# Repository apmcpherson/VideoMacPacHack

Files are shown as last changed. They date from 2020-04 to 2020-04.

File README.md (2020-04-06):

# VideoMacPacHack

The VideoMacPacHack is a clone of the Video Mac Pac, a PDS video card for the Macintosh Portable designed in 1991 by Computer Care Inc. The Video Mac Pac provides monochrome (1-bit) video on an external display, with several resolutions selectable by a control panel.

The VideoMacPacHack aims to replicate the Video Mac Pac using original parts where possible, with modern substitutions in  cases where original parts are hard to source (e.g. GAL, miniature relay), or where the original design was unknown (the video adapter board).

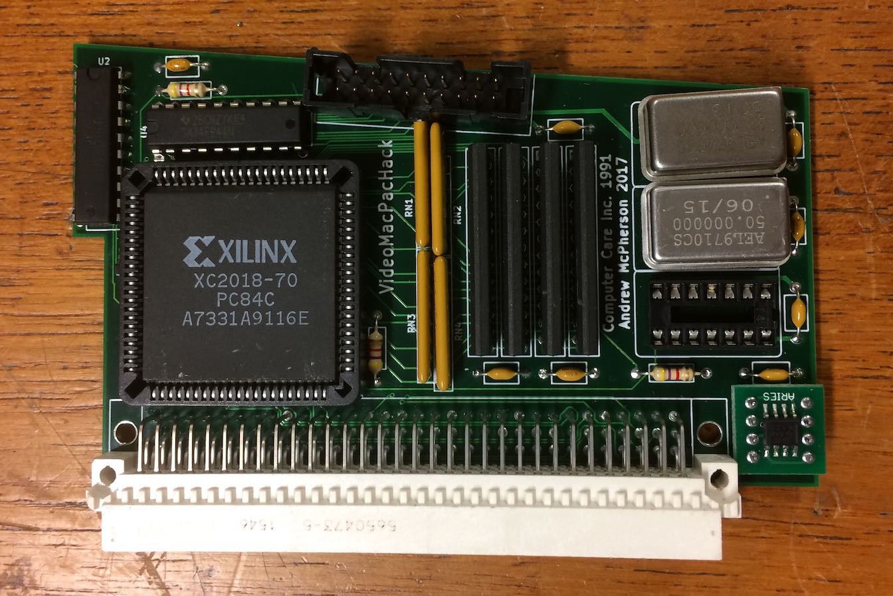
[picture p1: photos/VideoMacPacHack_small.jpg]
VideoMacPacHack


## Contents

* `hardware/VideoMacPac`: PCB design for the VideoMacPacHack, 4 layers, made in Kicad
* `hardware/VGA_adapter`: PCB design for the VGA breakout board, 2 layers, made in EAGLE
* `software`: Video Mac Pac Control Panel, needed to load the card firmware and select resolution
* `photos`: Photos of the original and clone card
* `documentation`: Technical information on the hardware and software

## System Requirements and Operation

The VideoMacPacHack fits the PDS slot of the Macintosh Portable. It has been successfully tested in both M5120 (non-backlit) and M5126 (backlit) Portables. Based on the address space used by the card, it will probably only work on Portables with less than 8MB of RAM installed.

The VideoMacPacHack (like the original Video Mac Pac) requires its associated control panel to run (see `software`). The external screen will become active when the control panel loads, provided the external video adapter is attached at boot. If the Portable is put to sleep, the external display will not work until reboot.

## Acknowledgments

The Video Mac Pac was created by Computer Care Inc. in 1991, apparently based on the Lapis DisplayServer.

The VideoMacPacHack was designed by [Andrew McPherson](https://github.com/apmcpherson) with encouragement from [Tom Stepleton](https://github.com/stepleton) based on hardware in his collection. In the interest of historical preservation it is released into the public domain, with no warranty of any sort.

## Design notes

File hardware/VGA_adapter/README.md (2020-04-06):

# VideoMacPac video adapter

These design materials are in the public domain, with no warranty whatsoever. See `documentation` on this repository for further design notes and `photos` for a photo of the assembled board.

## EAGLE files

* `VideoMacPac_adapter.sch`: EAGLE schematic
* `VideoMacPac_adapter.brd`: EAGLE PCB design
* `schematic.png`: image of the schematic

## Gerbers

This is a 2-layer PCB which can be fabricated from the files in the `gerbers` directory. It is a simple design which can be made on a mill with no soldermask as long as it has plated-through holes. The most important files are:

* `copper_top.gbr`: top copper
* `copper_bottom.gbr`: bottom copper
* `profile.gbr`: board outline
* `drill_1_16.xln`: Excellon drill file

## Bill of Materials

| Name | Value |
| --- | --- |
| C1-C2 | 0.1uF 0603 capacitors |
| IC1 | 74LVC245 (20-SOIC) bus transceiver |
| IC2 | MCP1700-3302T (SOT23) 3.3V regulator  |
| J1 | DB25 female |
| J2 | HD15 (VGA) female |
| R1-R3 | 133 ohm 0603 resistors |
| R4-R6 | 150 ohm 0603 resistors |
| R7 | 100 ohm 0603 resistor (could use 150) |

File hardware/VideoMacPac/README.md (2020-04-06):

# VideoMacPacHack

These design materials are in the public domain, with no warranty whatsoever. See `documentation` on this repository for further design notes.

## Kicad files

* `VideoMacPac.pro`: Kicad project
* `VideoMacPac.sch`: Kicad schematic
* `VideoMacPac.kicad_pcb`: Kicad PCB design
* `VideoMacPac_schematic.pdf`: Schematic in PDF format

## Gerbers

This a 4-layer PCB which can be fabricated from the files in the `gerbers` directory.

* `VideoMacPac-F.Cu.gbr`: top copper
* `VideoMacPac-In1.Cu.gbr`: inner layer 1 copper
* `VideoMacPac-In2.Cu.gbr`: inner layer 2 copper
* `VideoMacPac-B.Cu.gbr`: bottom copper
* `VideoMacPac-F.SilkS.gbr`: top silkscreen
* `VideoMacPac-F.Mask.gbr`: top soldermask
* `VideoMacPac-B.Mask.gbr`: bottom soldermask
* `VideoMacPac-Edge.Cuts.gbr`: board outline
* `VideoMacPac.drl`: Excellon drill file

## Bill of Materials

| Name | Value |
| --- | --- |
| C1-C8 | 0.1uF axial capacitors |
| J1 | 20-pin IDC header |
| J2 | 96-pin right-angle EuroDIN |
| R1-R4 | 4.7k resistors |
| RN1-RN2 | 3x47 ohm SIP resistor networks |
| RN3-RN4 | 4x47 ohm SIP resistor networks |
| U1 | XC2018-100-PC84 (faster can be used) |
| U2 | 74F521 (DIP) |
| U3 | 74AHCT1G00 (SOT23) |
| U4 | 74F244 (DIP) -- do not substitute |
| U5-U8 | MT42C4064Z-12 (faster can be used) |
| U9 | TPS2030 (DIP) |
| X1 | 36MHz 4-pin oscillator |
| X2 | 50.35MHz 4-pin oscillator |
| X3 | 57.2832MHz 4-pin oscillator |

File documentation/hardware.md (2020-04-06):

# Video Mac Pac hardware

The following document is based on an analysis and reverse engineering of the Video Mac Pac board. To date we have not found any original documentation on this design.

## Operation overview

The Video Mac Pac, designed in 1991 by Computer Care Inc., is a PDS expansion card for the Macintosh Portable (M5120 and M5126) that provides a second video output in addition to the Portable’s built-in screen. It supports 1-bit video at several resolutions:

* 640x872 (Apple Portait Display)
* 640x872 (Sunkyung FPD)
* 640x872 (Samsung FPD)
* 640x480 (Apple Monochrome Display)
* 640x480 (VGA)
* 800x600 (Super VGA)
* 528x348 (Mono TTL)
* 272x208 (TV/VCR)

These resolutions are selectable through the Video Mac Pac control panel which must be installed for the card to work.

The hardware design and software drivers appear to be closely related to the Lapis DisplayServer-SE video card. The card is based on a Xilinx CPLD whose firmware is loaded at boot by the control panel, along with VRAM and some glue logic for interfacing to the PDS slot and to the display.

## CPLD

The Video Mac Pac is based on the Xilinx `XC2018-100PC84` CPLD, which has the following specifications: 

* 84-pin PLCC package 
* 5V logic
* 1800 gates
* 74 I/Os
* 100ns toggle rate 

The size of a program configuration on the XC2018 is 17878 bits. There is no non-volatile storage either on the XC2018 or elsewhere on the Video Mac Pac, meaning that the CPLD configuration is downloaded by the Macintosh on power-up.

On the VMP, the XC2018 mode pins `M0, M1, M2` are configured as `101`, corresponding to Peripheral mode. In this mode, the program is clocked in 1 bit at a time on the `DIN` and `WRT` pins.

For comparison, the Lapis DisplayServer-SE is also based on the XC2018. The SE-DPD (capable of driving dual page displays) instead uses the `XC3020-70-PC84`. 

## VRAM

The VMP uses four Micron `MT42C4064Z-12` 64kx4 VRAM ICs. These are in a 24-pin ZIP package (i.e. SIP with staggered leads). Each VRAM chip handles 4 bits of a 16-bit data word. 

The CPLD maps the VRAM to the memory address space from `$720000` to `$73FFFF` (128k bytes in total).

## GAL

The CPLD must be programmed by the Macintosh using the Video Mac Pac control panel. A `GAL16V8-25LNC` IC on the board implements an address decoder for address `$740200` (binary `0111 010x xxxx xx1x xxxx xxxx`). 

The GAL also takes as input a sense line (active high) from the external video dongle. When the dongle is connected, address `$740200` is matched and `AS/` is low, the output (tied to the `WRT` pin on the CPLD) goes low. This feature is used to program the CPLD after power-on, after which point further communication takes place directly to the CPLD via the bus on the PDS slot.

If the dongle is not connected when the control panel loads, the CPLD will not be programmed and the video card will not operate until a restart takes place.

## PDS slot

See Apple's *Designing Cards and Drivers for the Macintosh Family* for the pinout of the Macintosh Portable PDS slot. The following pins of the PDS slot connect to the CPLD:

* Clock signal `16M`
* All address lines `A23-A0`
* Data line `D0` (connected to `DIN` to program the CPLD)
* Address strobe `/AS`
* Data strobes `/UDS` and `/LDS`
* Read/write signal `R/W`
* Acknowledge signals `/DTACK` and `/EXT.DTACK`
* Reset signal `/SYS.RST`

The following parts of the PDS slot connect directly to the VRAM:

* Data lines `D15-D0`, 4 bits per IC

All other VRAM pins are connected via the CPLD.

## Relay

The VMP contains a miniature 5V relay which is switched by way of the PDS signal `5/0V`. This powers down the card when the Portable goes to sleep.

When the Portable wakes from sleep, the CPLD program will be lost and it appears that a power cycle is required to enable the external screen.

## Oscillators

The VMP has 3 oscillator cans: 36MHz, 50.35MHz, 57.2832MHz. The 36MHz oscillator is socketed, while the other two are soldered. One of the three oscillator signals is chosen by the CPLD depending on the screen resolution. These provide the pixel clock for the video output.

The oscillators are not powered directly on the board. Rather, power to the oscillators is routed to a pin on the external video dongle connector, and the dongle routes the power back to the oscillators. This appears to be a power saving measure when the dongle is not connected.

In addition to the three oscillators, the card receives a 16MHz clock from the PDS slot.

## Outputs

The CPLD generates eight output logic signals which are buffered through a `74F244` octal buffer. These signals include:

* Three video signals. Our testing showed that these three always generate the same signal, as the card is 1-bit monochrome, but perhaps keeping separate signals was intended for a future design which would be full colour.
* Horizontal and vertical sync
* Three other signals which measure as constant high or low depending on the chosen resolution. These may have performed control functions for an external dongle (now lost).

The signals appear on a 20-pin header with the following pinout:

| pin | description | pin | description |
| --- | --- | --- | --- |
| 1 | oscillator +5V | 2 | +5V out |
| 3 | ground | 4 | sense input |
| 5 | ground | 6 | HSYNC |
| 7 | ground | 8 | VSYNC |
| 9 | ground | 10  | unknown 1 |
| 11  | ground | 12  | video 1 |
| 13  | ground | 14  | video 2 |
| 15  | ground | 16  | video 3 |
| 17  | ground | 18  | unknown 2 |
| 19  | ground | 20  | unknown 3 |

## Video Adapter Dongle

The VMP has a 20-pin IDC header, which connects by a ribbon cable to a DB25 male connector mounted in the rear cover of the Portable. This presumably connects to a dongle which provides the last step of signal conditioning and the correct pinout for the monitor in question.

We do not have the original dongle, however based on experimentation we have worked out its probable functions:

* The dongle provides a loopback between the +5V power supply and the power input to the oscillators. This is presumably to reduce power consumption when the dongle isn’t connected and the card is not in use.
* The DB25 contains a sense line to the GAL which is responsible for programming the CPLD. On the dongle, this line is pulled up to +5V, allowing the GAL to be programmed and the card to become operational only when the dongle is connected at boot.
* The dongle may provide level-shifting for driving analog monitors (e.g. VGA, Apple 13”). For TTL monitors a different dongle might have been used which passed through the video signal directly.

The pinout of the DB25 male is as follows:

| pin | description | pin | description |
| --- | --- | --- | --- |
| 1 | oscillator +5V | 14  | +5V out |
| 2 | ground | 15  | sense input |
| 3 | ground | 16  | HSYNC |
| 4 | ground | 17  | VSYNC |
| 5 | ground | 18  | unknown 1 |
| 6 | ground | 19  | video 1 |
| 7 | ground | 20  | video 2 |
| 8 | ground | 21  | video 3 |
| 9 | ground | 22  | unknown 2 |
| 10  | ground | 23  | unknown 3 |
| 11  | n/c | 24  | n/c |
| 12  | n/c | 25  | n/c |
| 13  | n/c | | |

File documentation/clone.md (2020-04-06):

# VideoMacPacHack

The following are implementation notes on cloning the Video Mac Pac PDS expansion card. The schematic and board layout can be found in the `hardware/VideoMacPac/` directory in this respository.

## Schematic

The schematic of the VideoMacPacHack conforms as closely as possible to the original VMP, with a few exceptions:

### Address decoder

On the VMP, a `GAL16V8` implements a relatively straightforward address decoder with 10 inputs (9 address lines plus an active sense signal) and 1 output (to the CPLD `WRT` pin). To avoid the need to recreate this custom IC, standard logic can be used instead. The basis of the current design is a `74F521` 8-bit address decoder. In addition to its 8 logic inputs, it has a 9th `OE/` input which can be used for one additional bit of decoding. 

However, one further bit is still required to replicate the functionality of the GAL. Because board space does not allow another DIP IC, a single-gate SMT IC is used instead: `74AHCT1G00`, a single 2-input NAND gate.

### Power switch

Miniature relays have been supplanted by analog power switch ICs. This design uses a `TPS2030` IC to achieve the same effect as the original relay. A DIP package is used in the VMPH design. However, SMT versions of the part appear to be more widely available and can be used with a DIP-SMT adapter.

### 74F244

This is a place where the original design should not be changed.

Initial experiments exchanged the `74F244` buffer IC for a nearly-equivalent `74HC244`. However, we found that the longer and more variable propagation delay on the `74HC244` caused vertical edges to show colour tints, as the edges on the three video channels were no longer aligned (the R, G and B lines have separate logic signals from the CPLD). The original 74F244 does not exhibit this problem.

## PCB Layout

The mechanical layout of the PCB follows the original VideoMacPac design, which is in turn based on Apple’s specifications in the Guide to the Macintosh Family Hardware. The component layout is broadly similar to the original.

The PCB is a 4-layer design, like the original VMP. The trace routing is electrically identical but does not follow the same geometry as the original. The original VideoMacPac design largely avoids vias, with traces crossing layers at existing through-hole pads. The VMPH alternative routing was done relatively quickly and has not sought to optimise the layout in this way.

The VMPH design attempts to use through-hole parts wherever possible. It was necessary to make a single exception for space reasons: U3 (`74AHCT1G00`), a single NAND gate which is used to provide one extra input to the address decoder in U2.

On the other hand, the video adapter dongle is made with SMT ICs and passives for compactness.

## Notes on Bill of Materials 

The VideoMacPacHack requires the following historical parts, which can sometimes be found as new old stock:

* 1x `XC2018-100-PC84` (84-pin PLCC): Xilinx CPLD
* 4x `MT42C4064Z-12` (24-pin ZIP): VRAM
* 5V 4-pin oscillator cans: 36MHz, 50.35MHz, 57.2832MHz (see below)

### CPLD

A `XC2018-70` was used in place of the `XC2018-100` with no adverse effects.

### VRAM and resistor networks

A `MT42C4064Z-10` was used in place of the `MT42C4064Z-12` in prototypes with no adverse effects.

The VRAM connects to the PDS data lines, but most signals go to the CPLD by way of 47 ohm resistors. On the VMP, 4 SIP resistor networks are used: two with 4 elements, two with 3 elements. If 3-element resistor networks are hard to find, 4-element versions can be used in those slots with the two pins on the end cut off.

### Oscillators

5V DIP oscillator cans are no longer available in as many frequencies as they once were. New old stock may need to be found for these frequencies. In most cases, similar but non-identical frequencies can be used with the effect of changing the refresh rate of the resolution. Driving a modern LCD monitor this would likely not be a problem. 

There appear to be limits to how far the frequencies can be stretched: for example, putting a 50MHz crystal in place of the 36MHz crystal produces no output at the affected resolutions.

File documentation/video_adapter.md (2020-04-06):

# Video Adapter Dongle

An adapter board is necessary to connect from the DB25 male on the back of the Portable to the monitor. The original dongle for the Video Mac Pac was lost, so this reconstruction is based on its apparent principles of operation and almost certain differs substantially from the original.

See the `hardware/VGA_adapter/` directory in this repository for the schematic and board layout of the adapter. 

## Detection Circuit

Connecting pins 14 and 15 on the DB25 (pins 2 and 4 on the 20-pin IDC) holds the sense line high and signals the presence of the dongle. 

In the schematic, a 100 ohm resistor is used between these as a precaution in case of incorrect insertion of the dongle, but this could probably be replaced with a simple short.

## Oscillator Power

Connecting pins 1 and 14 on the DB25 (pins 1 and 2 on the 20-pin IDC) provides +5V power to the oscillators which are needed to generate the video pixel clock.

## Buffering and Level Shifting

All signals from the card are 5V TTL. VGA signals need to be 0.7V or 1.0V maximum, depending on the standard. Level shifting is therefore required for the video signals. 

The sync signals remain at TTL levels and are passed through unchanged to the VGA connector.

### 3.3V regulator

While a simple voltage divider could reduce the 5V TTL video signal to the correct level, we find that the 5V line on the Portable fluctuates under load, which results in brightness variations and sometimes noise on the picture.

Instead, a 3.3V regulator is used to generate a stable reference voltage for the video signals. Each of the three video signals is buffered by a `74LVC245` level shifter, which produces 3.3V outputs. These are in turn divided down by a resistive voltage divider to meet VGA level and impedance requirements.

### Impedance

VGA expects a signal of up to 0.7V (1.0V in some variations), and an impedance of 75 ohms. The `74LVC245` has a rated output impedance of 15 ohms per buffer. We therefore use 133 ohms in series (closest available value to 135 ohms) and 150 ohms in parallel to produce a raw (unloaded) output of 3.3V/2 = 1.65V, with a source impedance of 150/2 = 75 ohms. When the monitor is connected, the 75 ohm load impedance reduces the video signal to 1.65V/2 = .825V.

For comparison: examining the video adapters for the Lapis DisplayServer cards shows that they used 150 ohms in series and 150 ohms in parallel from a 5V source to generate the video signal.

### Alternative approach

Three separate logic signals are used for the R, G, and B lines, which ultimately derive from three different pins on the CPLD. Slight timing shifts between the pins result in messy vertical edges in the image, with colour tints to the left or right of the line. 

In our later investigations, we found that the `74HC244` had too long and too variable a propagation delay and created noticeable clarity problems. The `74F244`, used on the original VideoMacPac design, does not show this problem. However, since the image is monochrome anyway, a relatively foolproof alternative is to drive all three buffers on the 74LVC245 with the same video signal.

## PCB Design

A 2-layer PCB was used with surface mount ICs and resistors for compactness. The DB25 and VGA connectors are on opposite ends of the board. 

The board could be enclosed in a plastic housing, or a version could be developed that goes directly from the 20-pin IDC to a VGA port. If this adapter were connected all the time, a switch could be used to toggle the sensing function that activates the card.

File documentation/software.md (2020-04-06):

# Video Mac Pac software

The *Video Mac Pac 4.1* control panel (CDEV) contains the drivers for the CPLD and several options for controlling the card. It allows a choice of resolutions, which take effect on power cycle -- not necessarily on reset since the CPLD needs to be powered down. 

The external screen can be configured to be on the left or the right of the Portable screen, and the menu bar can be moved between screens. The Portable screen can also be disabled. These changes also take effect at restart.

When the Portable sleeps, the CPLD settings are lost and the external screen does not reappear on wake. The machine needs to be rebooted for the CPLD code to be reloaded.

## Resolutions

The control panel offers a choice of the following resolutions (all at 1-bit monochrome). The VSYNC and HSYNC frequencies of each resolution were measured, and it was determined which of the three oscillator cans each resolution was derived from:

| Resolution | Name | Frequencies | Oscillator | Notes |
| --- | --- | --- | --- | --- |
| 640x872 | Apple Portrait | 68.8kHz H, 74.5Hz V | 57.2832MHz | |
| 640x872 | Sunkyung FPD | 68.8kHz H, 74.5Hz V	| 57.2832MHz | no video  |
| 640x872 | Samsung FPD	  | n/a | n/a | see below |
| 640x480 | Apple M/C | 39.9kHz? H, 76Hz? V	| 36MHz | see below |
| 640x480 | VGA | 31.5kHz H, 60Hz V | 50.35MHz | |
| 800x600 | Super VGA | 35.1kHz H, 56Hz V | 36MHz | |
| 528x348 | Mono TTL | 18.6kHz H, 50Hz V | 50.35MHz | no video  |
| 272x208 | TV/VCR | n/a | n/a | untested  |

The `Sunkyung FPD` and `TV/VCR` modes appear to use a different pin for video output, so they do not directly work with the dongle we have developed. Mono TTL could not be tested as it was below the scan range of the monitor for testing, but may also use a different video pin.

The `Samsung FPD` mode does not work because its corresponding `DS#1` resource is corrupt, missing a few bytes of the CPLD code.

The `Apple M/C` mode produces the wrong frequenceis for the Apple Monochrome Monitor. This mode may expect a different oscillator to be installed in the 36MHz socket, e.g. 31.5MHz, to produce a 66.7Hz refresh as expected.

## CDEV Resources

The Video Mac Pac control panel (CDEV) appears to be derived from the Lapis DisplayServer CDEV, which is used in several Lapis video cards for the Macintosh SE and later machines. 

Some of the important resources in the CDEV include:

* `Glue`: Holds 68k code implementing the display driver and hardware communication.
* `DS#1`: There are several such resources in the CDEV. Each one corresponds to a display resolution.
	* Offset `$92`: Holds the length of the CPLD code in bytes. The value in each case is `$8BC`: 2236 bytes, or 17888 bits. The XC2018 has a program space of 17878 bits.
	* Offset `$94`: CPLD bit stream begins
* `UVDS`: Holds the information on the current configuration ID (referring to an ID of a `DS#1` resource) and the settings for display arrangement, menu bar, and whether the internal screen is used.

For comparison: `DS#1` resources can also be found in the Lapis Dual Screen Software INIT. The DisplayServer PDS/30 CDEV contains `DS#4` resources, and the DisplayServer II-DPD CDEV contains `DS#6` resources, which appear to operate on similar principles. In principle, it might be possible to find CPLD code to support other resolutions from another CDEV or to reverse engineer it with contemporary Xilinx development tools.

## Memory-Mapped Addressing

The Macintosh Portable is a 68000 machine with 24-bit addressing. It reserves address range `$000000` to `$8FFFFF` for RAM (for a maximum of 9MB total).

On the Video Mac Pac, I/O is memory-mapped with the lowest region starting at `$720000`. This implies that the VMP will not function correctly if more than 7MB of RAM is installed in the Portable. (The largest factory configuration was 4MB (1MB onboard + 3MB expansion), but modern expansion cards are available providing up to 9MB total RAM.)

An analysis of the CDEV shows the following addresses in use: 

* `$720000`: VRAM base, addressable once CPLD code is loaded
	* Maximum length `$20000` (128 kB = max 1M pixels)
	* `$73FFEA` is used in the CDEV for a special checksum word, `BECK`, which is written and subsequently read to detect the presence of the card
	* `$73FFEE` is used in the CDEV to hold the ID of the current `DS#1` resource which contains information on the screen resolution
	* These two checks also serve to confirm that the CPLD has been programmed, since the VRAM is only accessible on the bus by way of the CPLD.
* `$740000`: unknown function
	* This address is referenced in various places in the CDEV code. For example, before the CPLD code is loaded by writing it out to `$740200`, the CDEV writes `$FF` to address `$740000`. However, it is not clear what the function of this write is or whether the address has any specific meaning to the hardware.
* `$740200`: `WRT` pin on CPLD
	* Any memory access to this address causes the GAL to bring the `WRT` pin on the CPLD low. Because data line `D0` is attached to the `DIN` pin of the CPLD, the practical effect is that each write to `$740200` shifts in a single bit of the CPLD program. 
	
The programming procedure for the CPLD thus consists of the following for each byte of the `DS#1` resource:

* Write byte to `$740200`
* Shift byte 1 bit right
* Write again
* Repeat the above 8 times in total, then move to the next byte

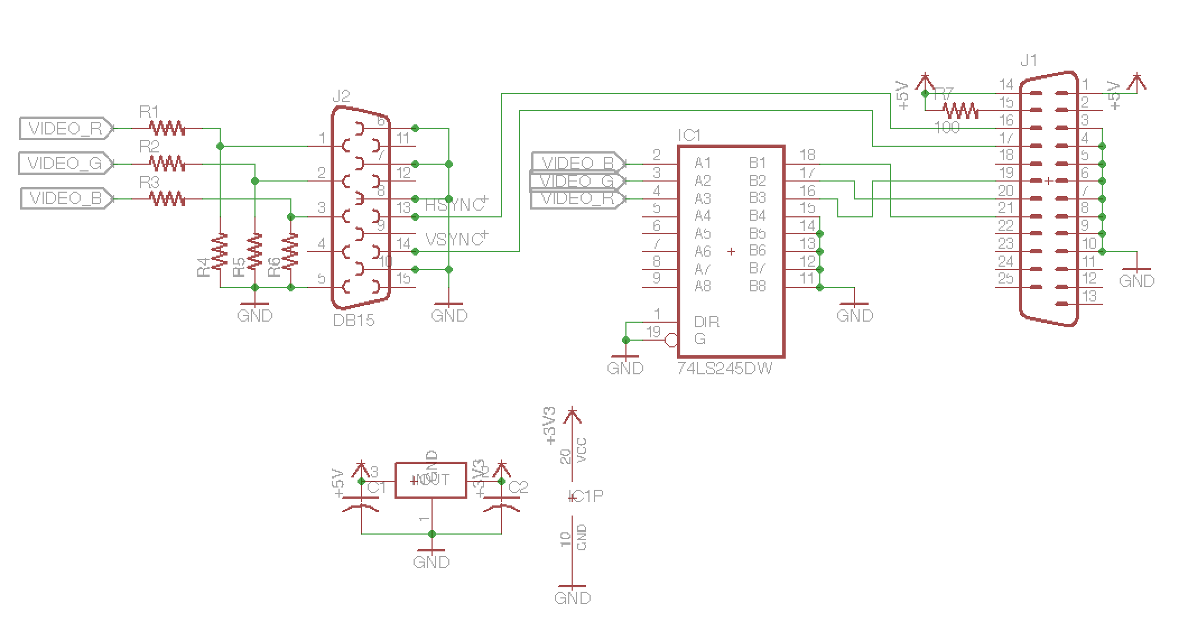
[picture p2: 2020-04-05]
hardware/VGA_adapter/schematic.png

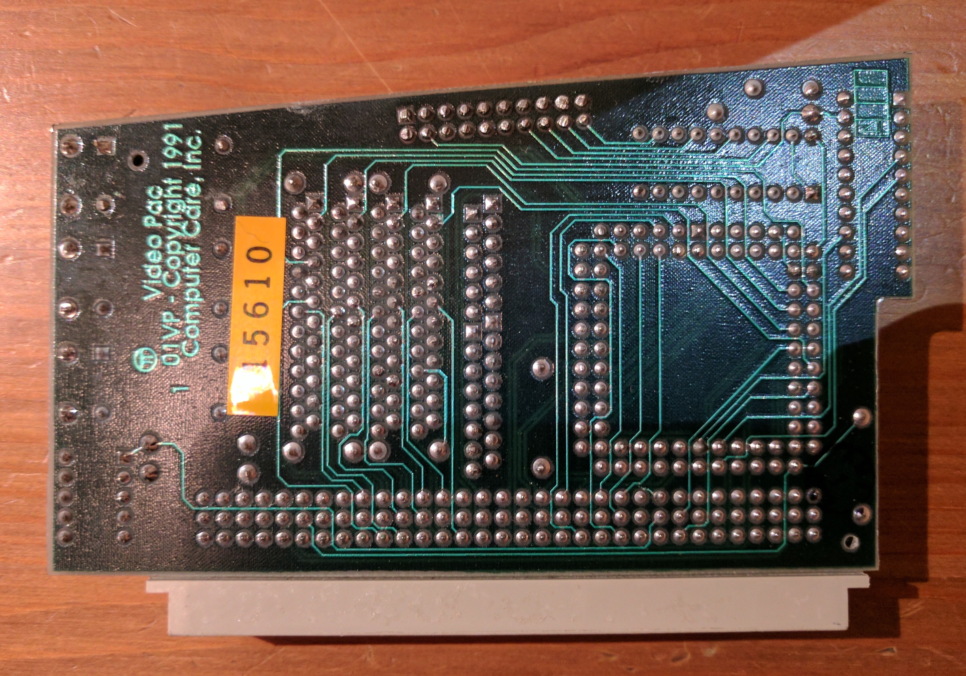
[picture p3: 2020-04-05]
photos/VideoMacPac_bottom.jpg

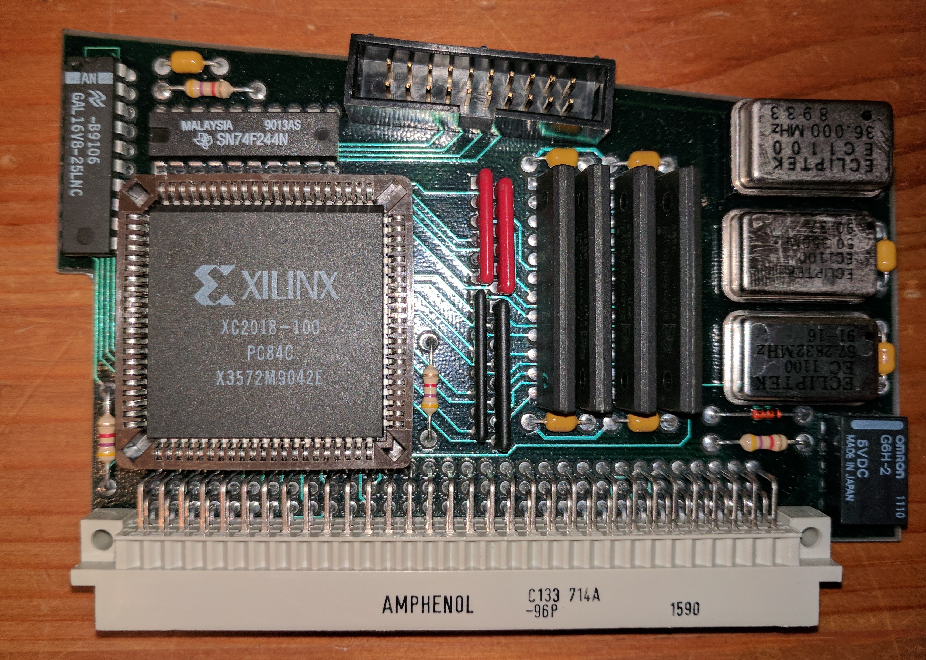
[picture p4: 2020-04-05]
photos/VideoMacPac_top.jpg

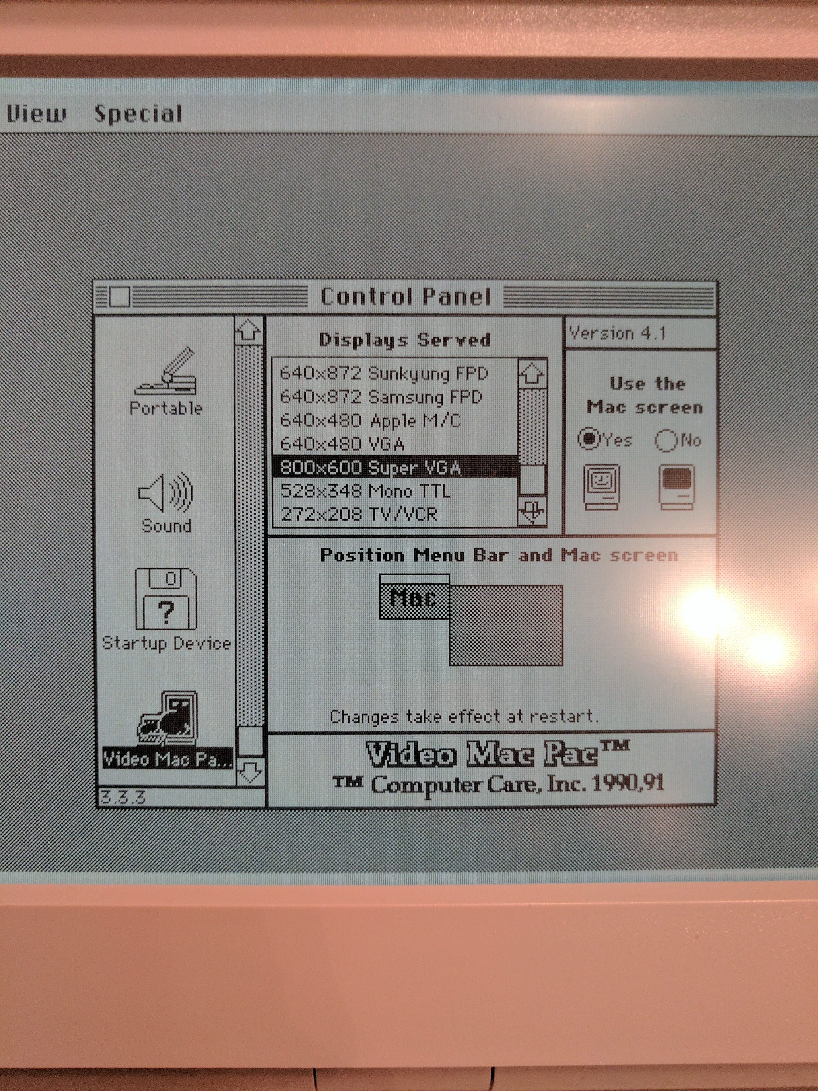
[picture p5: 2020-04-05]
photos/ControlPanel.jpg

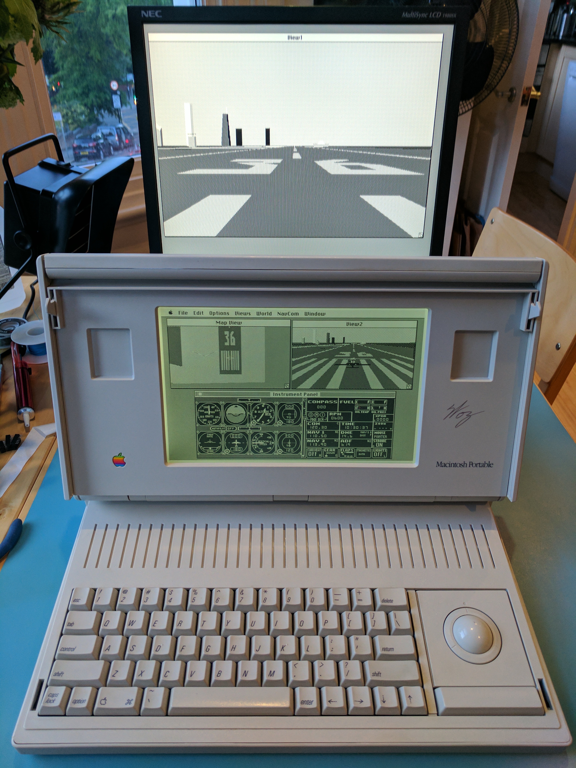
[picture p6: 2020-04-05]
photos/DualScreen.jpg

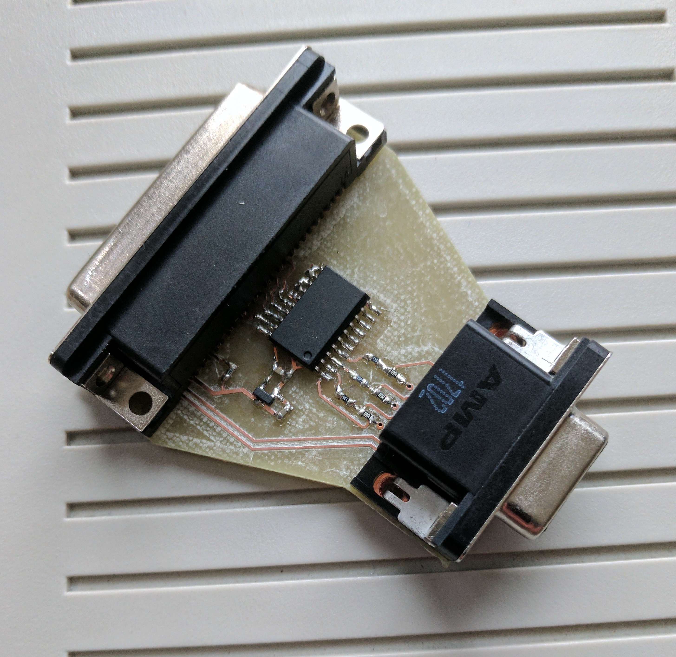
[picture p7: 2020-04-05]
photos/VGA_adapter.jpg

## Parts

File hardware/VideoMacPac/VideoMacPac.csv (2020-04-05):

Reference | Value | Footprint | Datasheet
U4 | 74LS244 | Housings_DIP:DIP-20_W7.62mm
U1 | XC2018-PC84 | Sockets:PLCC84
J2 | C96ABC | Connectors:C96ABCMD
R2 | 4.7k | Resistors_THT:R_Axial_DIN0207_L6.3mm_D2.5mm_P10.16mm_Horizontal
R3 | 4.7k | Resistors_THT:R_Axial_DIN0207_L6.3mm_D2.5mm_P10.16mm_Horizontal
X1 | ACO-36MHz | Oscillators:Oscillator_DIP-14
U2 | 74F521 | Housings_DIP:DIP-20_W7.62mm
RN1 | 47x3 | Resistors_THT:R_Array_SIP6
RN2 | 47x3 | Resistors_THT:R_Array_SIP6
RN3 | 47x4 | Resistors_THT:R_Array_SIP8
RN4 | 47x4 | Resistors_THT:R_Array_SIP8
U5 | 42C4064
U6 | 42C4064
U7 | 42C4064
U8 | 42C4064
J1 | CONN_02X10 | Connectors:IDC_Header_Straight_20pins
C1 | 0.1uF | Capacitors_THT:C_Axial_L5.1mm_D3.1mm_P7.50mm_Horizontal
C2 | 0.1uF | Capacitors_THT:C_Axial_L5.1mm_D3.1mm_P7.50mm_Horizontal
C3 | 0.1uF | Capacitors_THT:C_Axial_L5.1mm_D3.1mm_P7.50mm_Horizontal
X2 | ACO-50.35MHz | Oscillators:Oscillator_DIP-14
X3 | ACO-57.2832MHz | Oscillators:Oscillator_DIP-14
R4 | 4.7k | Resistors_THT:R_Axial_DIN0207_L6.3mm_D2.5mm_P10.16mm_Horizontal
R1 | 4.7k | Resistors_THT:R_Axial_DIN0207_L6.3mm_D2.5mm_P10.16mm_Horizontal
C4 | 0.1uF | Capacitors_THT:C_Axial_L5.1mm_D3.1mm_P7.50mm_Horizontal
C5 | 0.1uF | Capacitors_THT:C_Axial_L5.1mm_D3.1mm_P7.50mm_Horizontal
C6 | 0.1uF | Capacitors_THT:C_Axial_L5.1mm_D3.1mm_P7.50mm_Horizontal
C7 | 0.1uF | Capacitors_THT:C_Axial_L5.1mm_D3.1mm_P7.50mm_Horizontal
C8 | 0.1uF | Capacitors_THT:C_Axial_L5.1mm_D3.1mm_P7.50mm_Horizontal
U3 | 74AHCT1G00 | TO_SOT_Packages_SMD:SOT-23-5
U9 | TPS2030 | Housings_DIP:DIP-8_W7.62mm
C9 | 0.1uF | Capacitors_THT:C_Axial_L5.1mm_D3.1mm_P7.50mm_Horizontal

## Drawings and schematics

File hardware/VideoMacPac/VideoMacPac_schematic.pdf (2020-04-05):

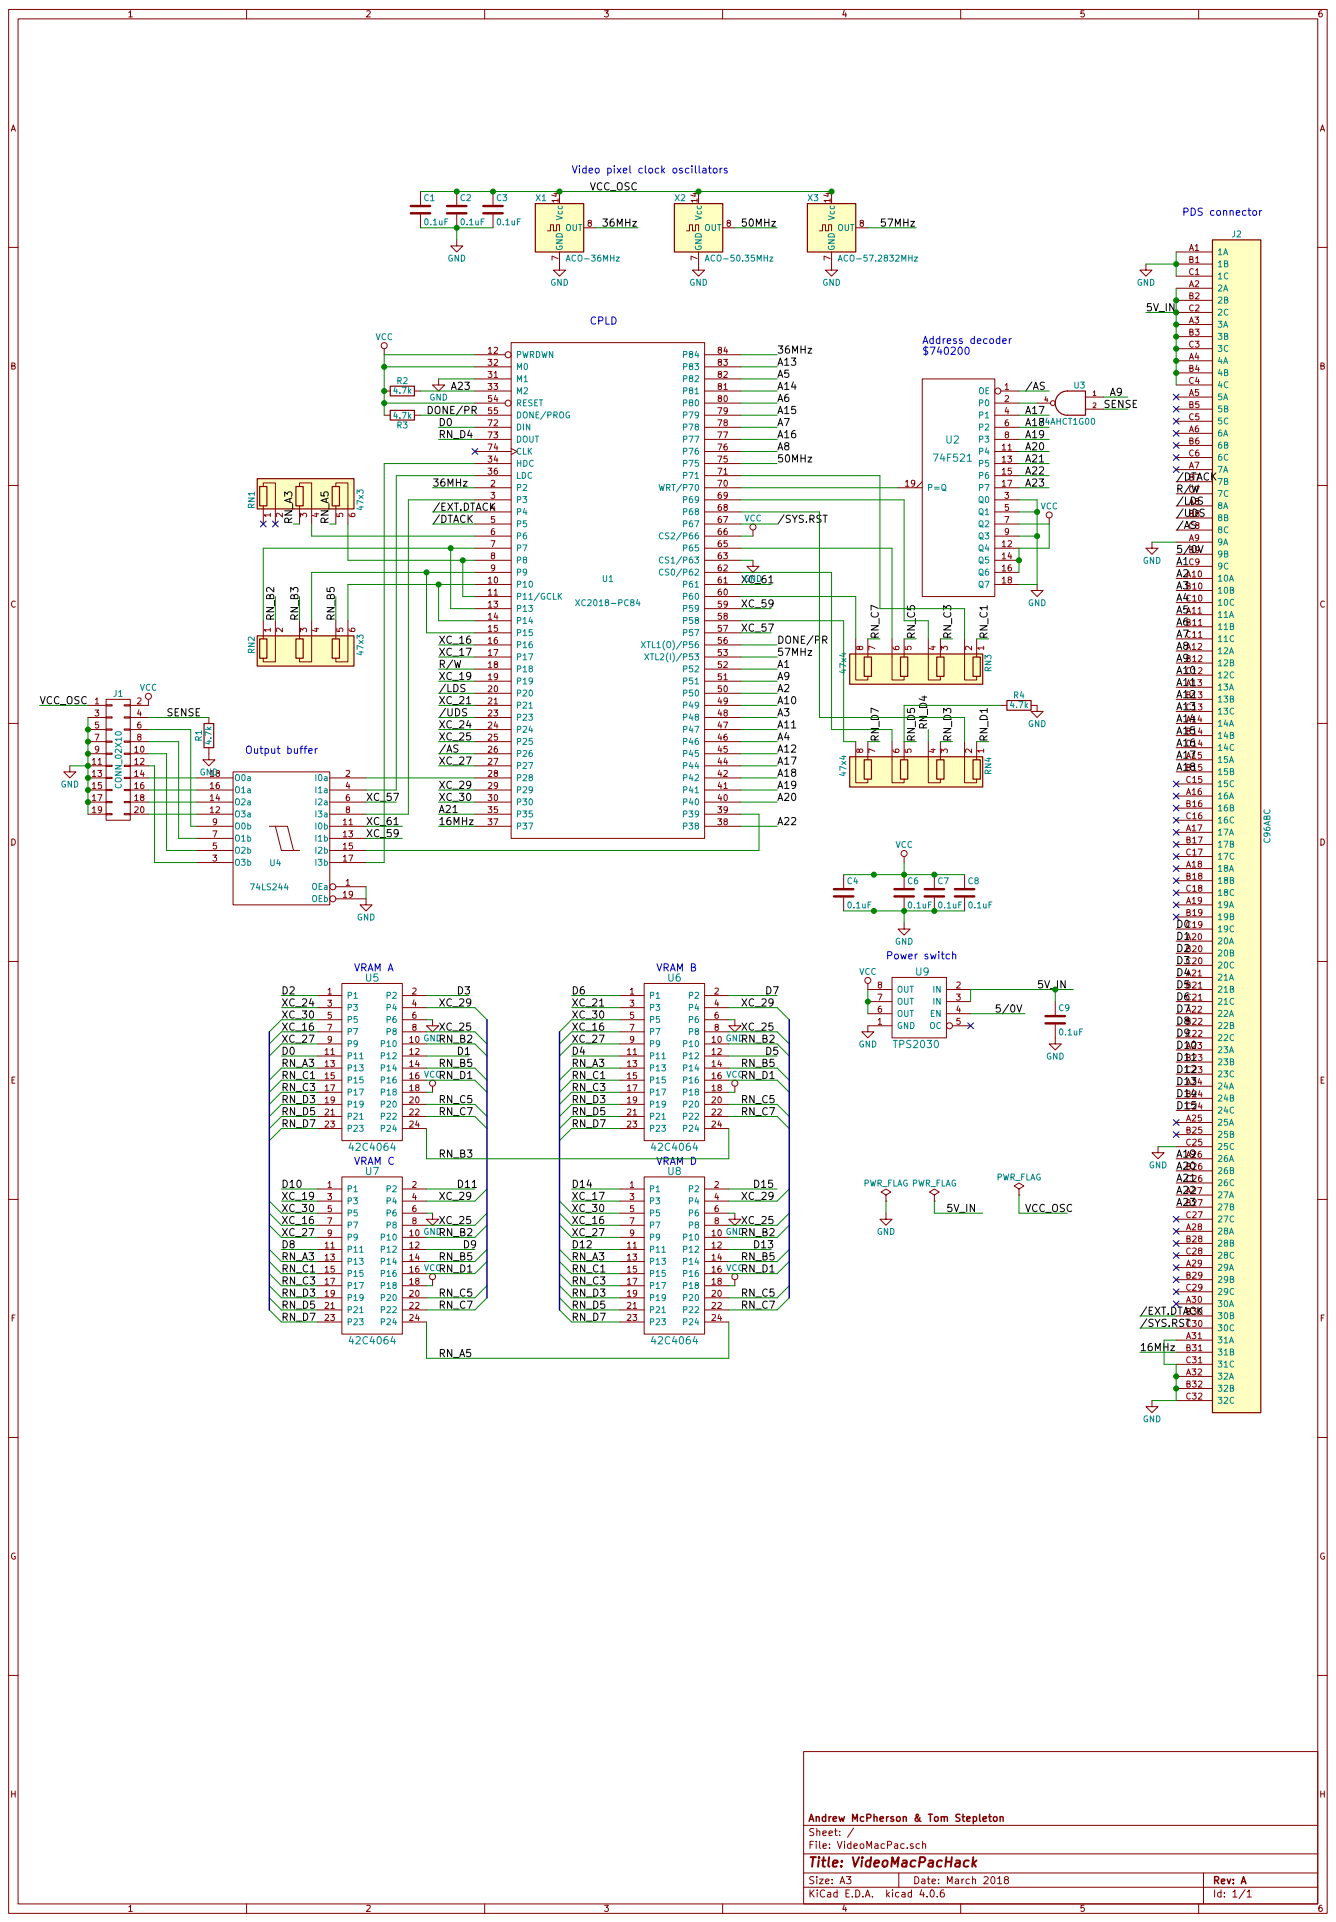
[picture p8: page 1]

Video pixel clock oscillators
VCC GND 1

7 OUT 8 Vcc X3 14 ACO-57.2832MHz 50MHz 57MHz GND GND XC_16

7 OUT 8 Vcc X1 14 ACO-36MHz OE 1 P0 2 Q0 3 P1 4 Q1 5 P2 6 Q2 7 P3 8 Q3 9 P4 11 Q4 12 P5 13 Q5 14 P6 15 Q6 16 P7 17 Q7 18 P=Q 19 U2

7 OUT 8 Vcc X2 14 ACO-50.35MHz GND

15 | 16 | XC_29
17 | 18 | XC_30
19 | 20 | A21

File: VideoMacPac.sch Sheet: / Andrew McPherson & Tom Stepleton

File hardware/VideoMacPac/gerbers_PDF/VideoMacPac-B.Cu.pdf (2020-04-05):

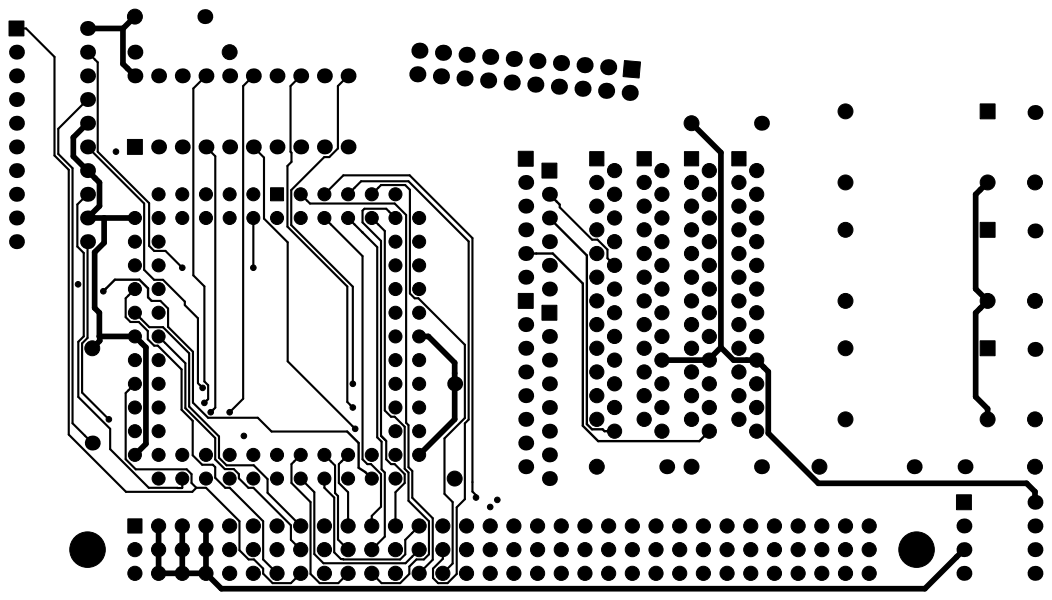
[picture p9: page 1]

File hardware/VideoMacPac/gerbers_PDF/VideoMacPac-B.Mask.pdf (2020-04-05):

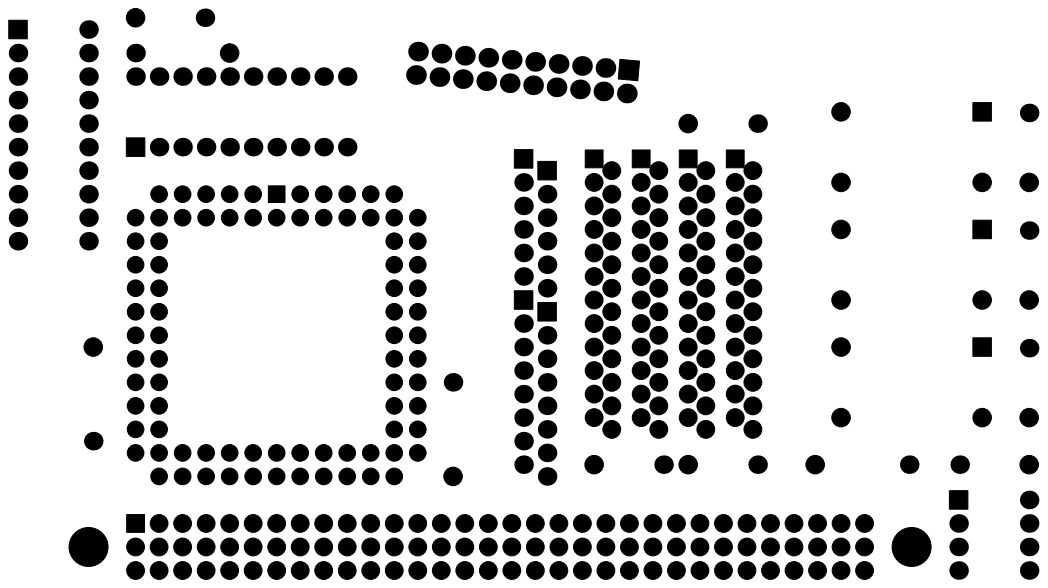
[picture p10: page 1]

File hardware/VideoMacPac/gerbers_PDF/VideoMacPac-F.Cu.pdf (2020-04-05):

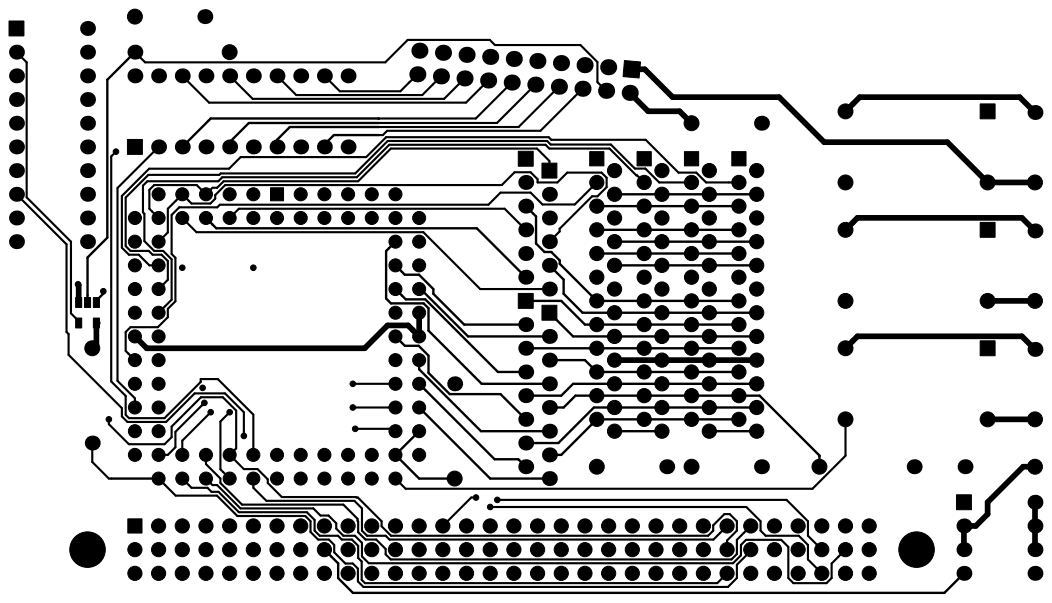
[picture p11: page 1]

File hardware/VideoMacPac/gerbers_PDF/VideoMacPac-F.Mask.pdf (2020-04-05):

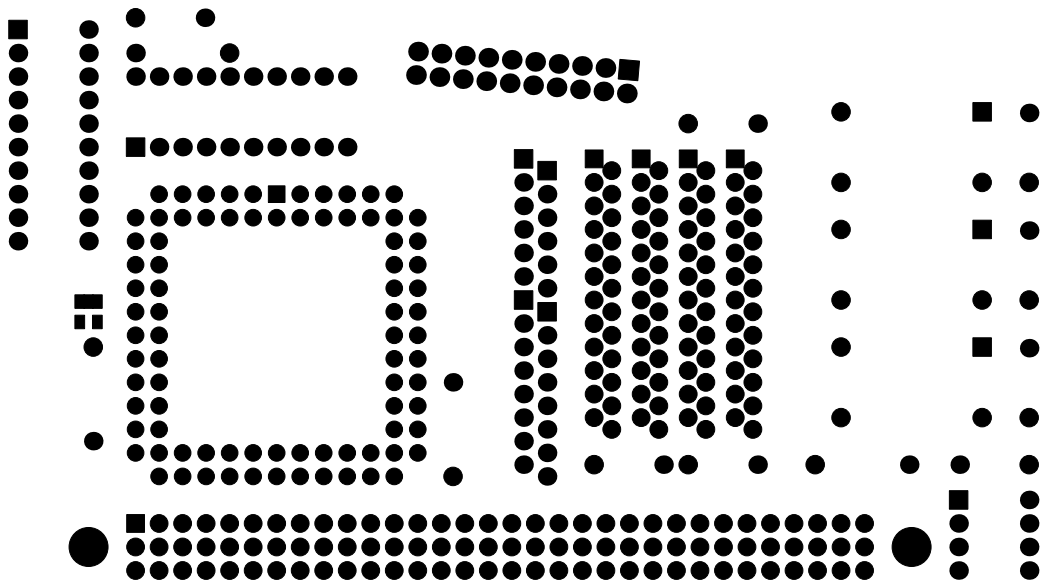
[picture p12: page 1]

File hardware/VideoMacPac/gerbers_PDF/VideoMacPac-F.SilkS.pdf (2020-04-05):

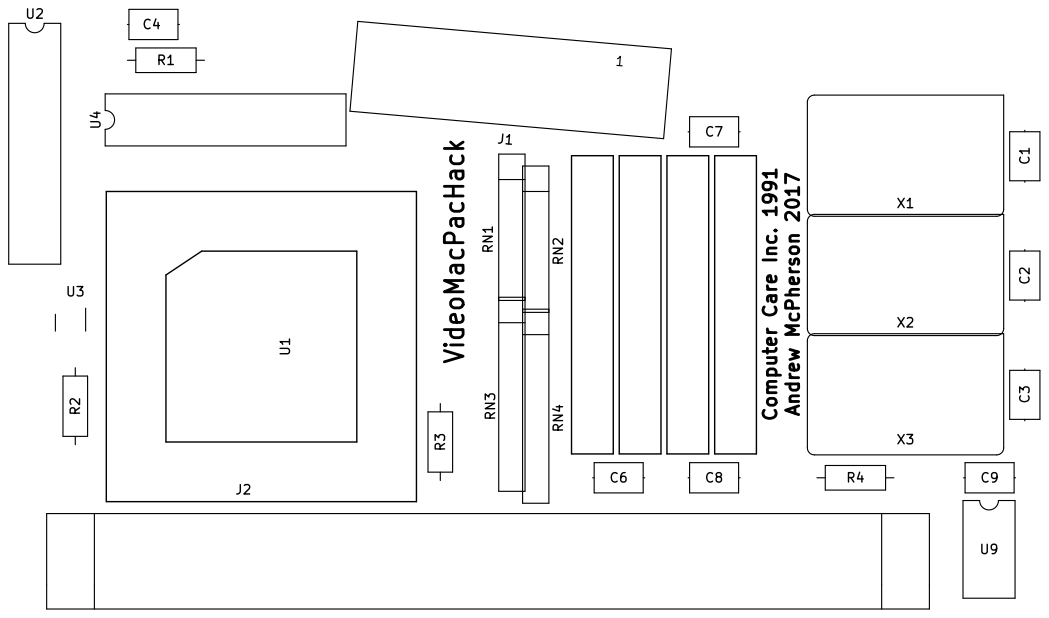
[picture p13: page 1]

Computer Care Inc. 1991 Andrew McPherson 2017 VideoMacPacHack

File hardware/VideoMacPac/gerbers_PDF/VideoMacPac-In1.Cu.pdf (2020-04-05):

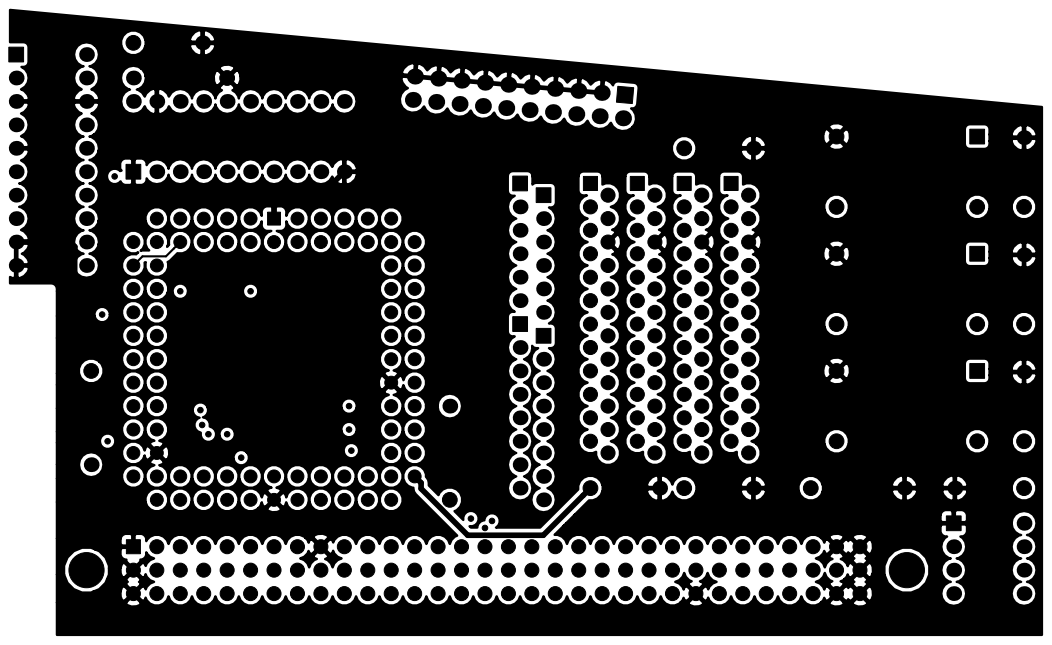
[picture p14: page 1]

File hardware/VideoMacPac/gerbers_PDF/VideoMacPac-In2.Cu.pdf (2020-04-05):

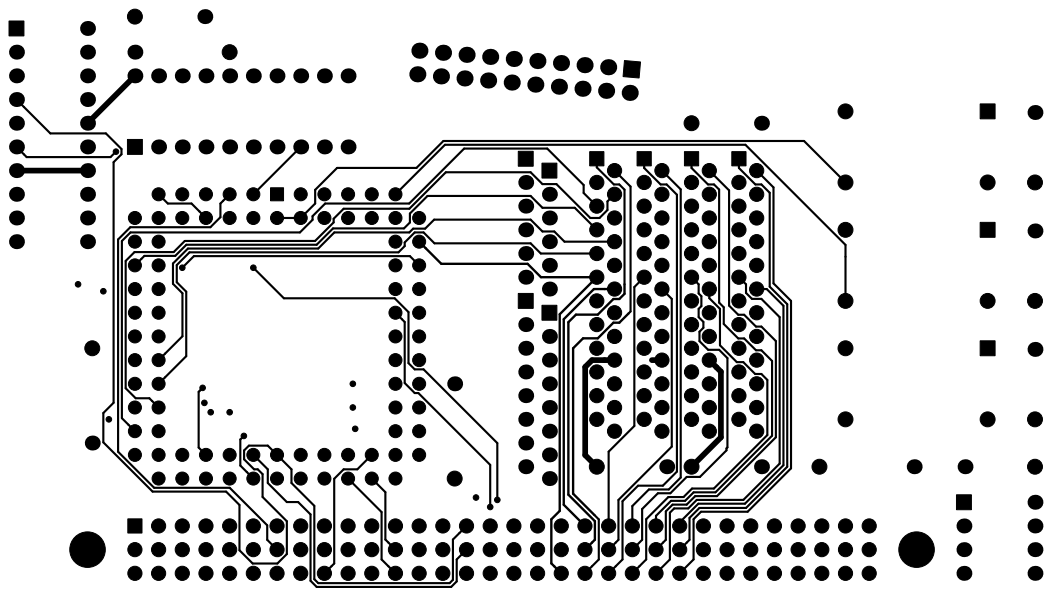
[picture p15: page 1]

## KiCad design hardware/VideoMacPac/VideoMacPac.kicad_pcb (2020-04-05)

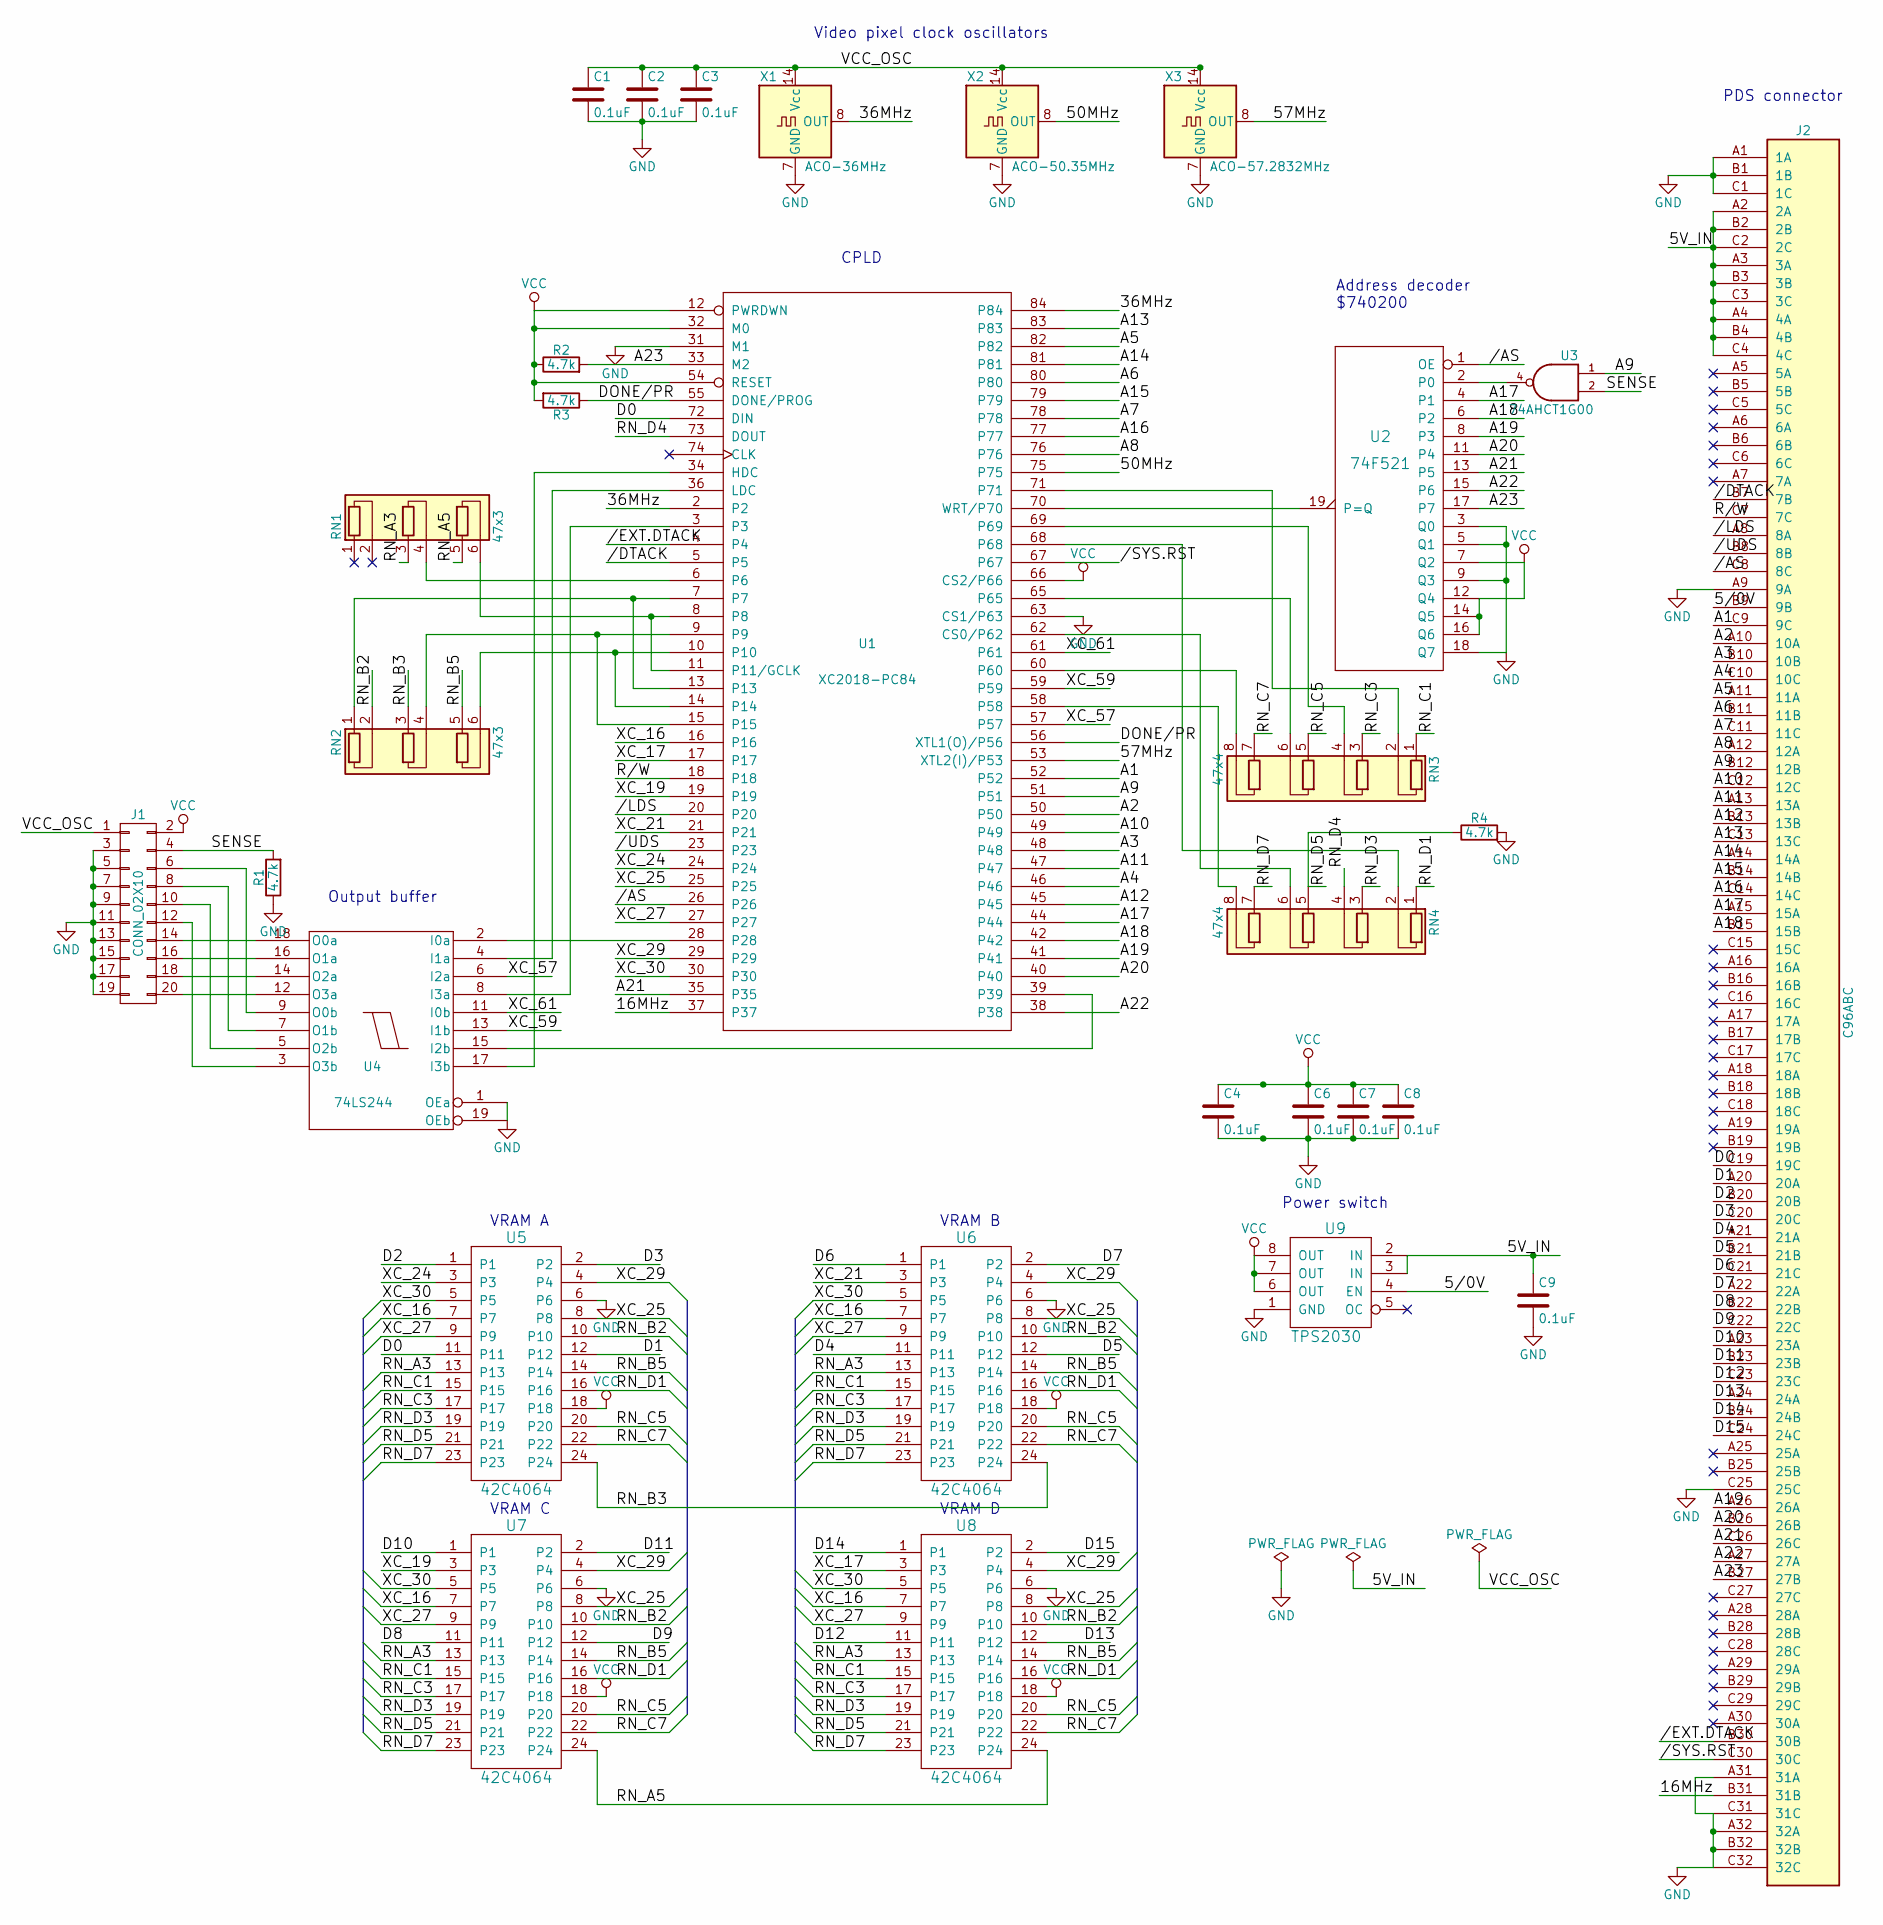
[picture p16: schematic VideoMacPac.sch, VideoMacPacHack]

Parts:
C1, C2, C3, C4, C6, C7, C8, C9: 0.1uF; C_Axial_L5.1mm_D3.1mm_P7.50mm_Horizontal
J1: CONN_02X10; IDC_Header_Straight_20pins
J2: C96ABC; C96ABCMD
R1, R2, R3, R4: 4.7k; R_Axial_DIN0207_L6.3mm_D2.5mm_P10.16mm_Horizontal
RN1, RN2: 47x3; R_Array_SIP6
RN3, RN4: 47x4; R_Array_SIP8
U1: XC2018-PC84; PLCC84
U2: 74F521; DIP-20_W7.62mm
U3: 74AHCT1G00; SOT-23-5
U4: 74LS244; DIP-20_W7.62mm
U5, U6, U7, U8: 42C4064; SIP24
U9: TPS2030; DIP-8_W7.62mm
X1: ACO-36MHz; Oscillator_DIP-14
X2: ACO-50.35MHz; Oscillator_DIP-14
X3: ACO-57.2832MHz; Oscillator_DIP-14

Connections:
/5/0V: J2.B9 (9B), U9.4 (EN)
/5V_IN: C9.1, J2.A2 (2A), J2.A3 (3A), J2.A4 (4A), J2.B2 (2B), J2.B3 (3B), J2.B4 (4B), J2.C2 (2C), J2.C3 (3C), J2.C4 (4C), U9.2 (IN), U9.3 (IN)
/16MHz: J2.B31 (31B), U1.37
/36MHz: U1.2, U1.84, X1.8 (OUT)
/50MHz: U1.75, X2.8 (OUT)
/57MHz: U1.53 (XTL2(I)/P53), X3.8 (OUT)
//AS: J2.C8 (8C), U1.26, U2.1 (OE)
//DTACK: J2.B7 (7B), U1.5
//EXT.DTACK: J2.B30 (30B), U1.4
//LDS: J2.A8 (8A), U1.20
//SYS.RST: J2.C30 (30C), U1.67
//UDS: J2.B8 (8B), U1.23
/A1: J2.C9 (9C), U1.52
/A2: J2.A10 (10A), U1.50
/A3: J2.B10 (10B), U1.48
/A4: J2.C10 (10C), U1.46
/A5: J2.A11 (11A), U1.82
/A6: J2.B11 (11B), U1.80
/A7: J2.C11 (11C), U1.78
/A8: J2.A12 (12A), U1.76
/A9: J2.B12 (12B), U1.51, U3.1
/A10: J2.C12 (12C), U1.49
/A11: J2.A13 (13A), U1.47
/A12: J2.B13 (13B), U1.45
/A13: J2.C13 (13C), U1.83
/A14: J2.A14 (14A), U1.81
/A15: J2.B14 (14B), U1.79
/A16: J2.C14 (14C), U1.77
/A17: J2.A15 (15A), U1.44, U2.4 (P1)
/A18: J2.B15 (15B), U1.42, U2.6 (P2)
/A19: J2.A26 (26A), U1.41, U2.8 (P3)
/A20: J2.B26 (26B), U1.40, U2.11 (P4)
/A21: J2.C26 (26C), U1.35, U2.13 (P5)
/A22: J2.A27 (27A), U1.38, U2.15 (P6)
/A23: J2.B27 (27B), R2.2, U1.33 (M2), U2.17 (P7)
/D0: J2.C19 (19C), U1.72 (DIN), U5.11
/D1: J2.A20 (20A), U5.12
/D2: J2.B20 (20B), U5.1
/D3: J2.C20 (20C), U5.2
/D4: J2.A21 (21A), U6.11
/D5: J2.B21 (21B), U6.12
/D6: J2.C21 (21C), U6.1
/D7: J2.A22 (22A), U6.2
/D8: J2.B22 (22B), U7.11
/D9: J2.C22 (22C), U7.12
/D10: J2.A23 (23A), U7.1
/D11: J2.B23 (23B), U7.2
/D12: J2.C23 (23C), U8.11
/D13: J2.A24 (24A), U8.12
/D14: J2.B24 (24B), U8.1
/D15: J2.C24 (24C), U8.2
/DONE/PR: R3.1, U1.55 (DONE/PROG), U1.56 (XTL1(O)/P56)
/R/W: J2.C7 (7C), U1.18
/RN_A3: RN1.3 (R2.1), U5.13, U6.13, U7.13, U8.13
/RN_A5: RN1.5 (R3.1), U7.24, U8.24
/RN_B2: RN2.2 (R1.2), U5.10, U6.10, U7.10, U8.10
/RN_B3: RN2.3 (R2.1), U5.24, U6.24
/RN_B5: RN2.5 (R3.1), U5.14, U6.14, U7.14, U8.14
/RN_C1: RN3.1 (R1.1), U5.15, U6.15, U7.15, U8.15
/RN_C3: RN3.3 (R2.1), U5.17, U6.17, U7.17, U8.17
/RN_C5: RN3.5 (R3.1), U5.20, U6.20, U7.20, U8.20
/RN_C7: RN3.7 (R4.1), U5.22, U6.22, U7.22, U8.22
/RN_D1: RN4.1 (R1.1), U5.16, U6.16, U7.16, U8.16
/RN_D3: RN4.3 (R2.1), U5.19, U6.19, U7.19, U8.19
/RN_D4: RN4.4 (R2.2), U1.73 (DOUT)
/RN_D5: R4.1, RN4.5 (R3.1), U5.21, U6.21, U7.21, U8.21
/RN_D7: RN4.7 (R4.1), U5.23, U6.23, U7.23, U8.23
/SENSE: J1.4, R1.2, U3.2
/VCC_OSC: C1.1, C2.1, C3.1, J1.1, X1.14 (Vcc), X2.14 (Vcc), X3.14 (Vcc)
/XC_16: U1.16, U5.7, U6.7, U7.7, U8.7
/XC_17: U1.17, U8.3
/XC_19: U1.19, U7.3
/XC_21: U1.21, U6.3
/XC_24: U1.24, U5.3
/XC_25: U1.25, U5.8, U6.8, U7.8, U8.8
/XC_27: U1.27, U5.9, U6.9, U7.9, U8.9
/XC_29: U1.29, U5.4, U6.4, U7.4, U8.4
/XC_30: U1.30, U5.5, U6.5, U7.5, U8.5
/XC_57: U1.57, U4.6 (I2a)
/XC_59: U1.59, U4.13 (I1b)
/XC_61: U1.61, U4.11 (I0b)
GND: C1.2, C2.2, C3.2, C4.2, C6.2, C7.2, C8.2, C9.2, J1.3, J1.5, J1.7, J1.9, J1.11, J1.13, J1.15, J1.17, J1.19, J2.A1 (1A), J2.A9 (9A), J2.A31 (31A), J2.A32 (32A), J2.B1 (1B), J2.B32 (32B), J2.C1 (1C), J2.C25 (25C), J2.C31 (31C), J2.C32 (32C), R1.1, R4.2, U1.1 (GND), U1.31 (M1), U1.43 (GND), U1.63 (CS1/P63), U2.3 (Q0), U2.5 (Q1), U2.9 (Q3), U2.10 (GND), U2.18 (Q7), U3.3 (GND), U4.1 (OEa), U4.10 (GND), U4.19 (OEb), U5.6, U6.6, U7.6, U8.6, U9.1 (GND), X1.7 (GND), X2.7 (GND), X3.7 (GND)
unnamed: J1.6, U4.9 (O0b)
unnamed: J1.8, U4.7 (O1b)
unnamed: J1.10, U4.5 (O2b)
unnamed: J1.12, U4.3 (O3b)
unnamed: J1.14, U4.18 (O0a)
unnamed: J1.16, U4.16 (O1a)
unnamed: J1.18, U4.14 (O2a)
unnamed: J1.20, U4.12 (O3a)
unnamed: RN1.4 (R2.2), U1.6
unnamed: RN1.6 (R3.2), U1.8, U1.11 (P11/GCLK)
unnamed: RN2.1 (R1.1), U1.7, U1.13
unnamed: RN2.4 (R2.2), U1.9, U1.15
unnamed: RN2.6 (R3.2), U1.10, U1.14
unnamed: RN3.2 (R1.2), U1.71
unnamed: RN3.4 (R2.2), U1.69
unnamed: RN3.6 (R3.2), U1.65
unnamed: RN3.8 (R4.2), U1.60
unnamed: RN4.2 (R1.2), U1.68
unnamed: RN4.6 (R3.2), U1.62 (CS0/P62)
unnamed: RN4.8 (R4.2), U1.58
unnamed: U1.3, U4.8 (I3a)
unnamed: U1.28, U4.2 (I0a)
unnamed: U1.34 (HDC), U4.17 (I3b)
unnamed: U1.36 (LDC), U4.4 (I1a)
unnamed: U1.39, U4.15 (I2b)
unnamed: U1.70 (WRT/P70), U2.19 (P=Q)
unnamed: U2.2 (P0), U3.4
VCC: C4.1, C6.1, C7.1, C8.1, J1.2, R2.1, R3.2, U1.12 (PWRDWN), U1.22 (VCC), U1.32 (M0), U1.54 (RESET), U1.64 (VCC), U1.66 (CS2/P66), U2.7 (Q2), U2.12 (Q4), U2.14 (Q5), U2.16 (Q6), U2.20 (VCC), U3.5 (VCC), U4.20 (VCC), U5.18, U6.18, U7.18, U8.18, U9.6 (OUT), U9.7 (OUT), U9.8 (OUT)

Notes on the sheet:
VRAM A
VRAM B
VRAM C
VRAM D
Power switch
Address decoder $740200
Output buffer
CPLD
Video pixel clock oscillators
PDS connector

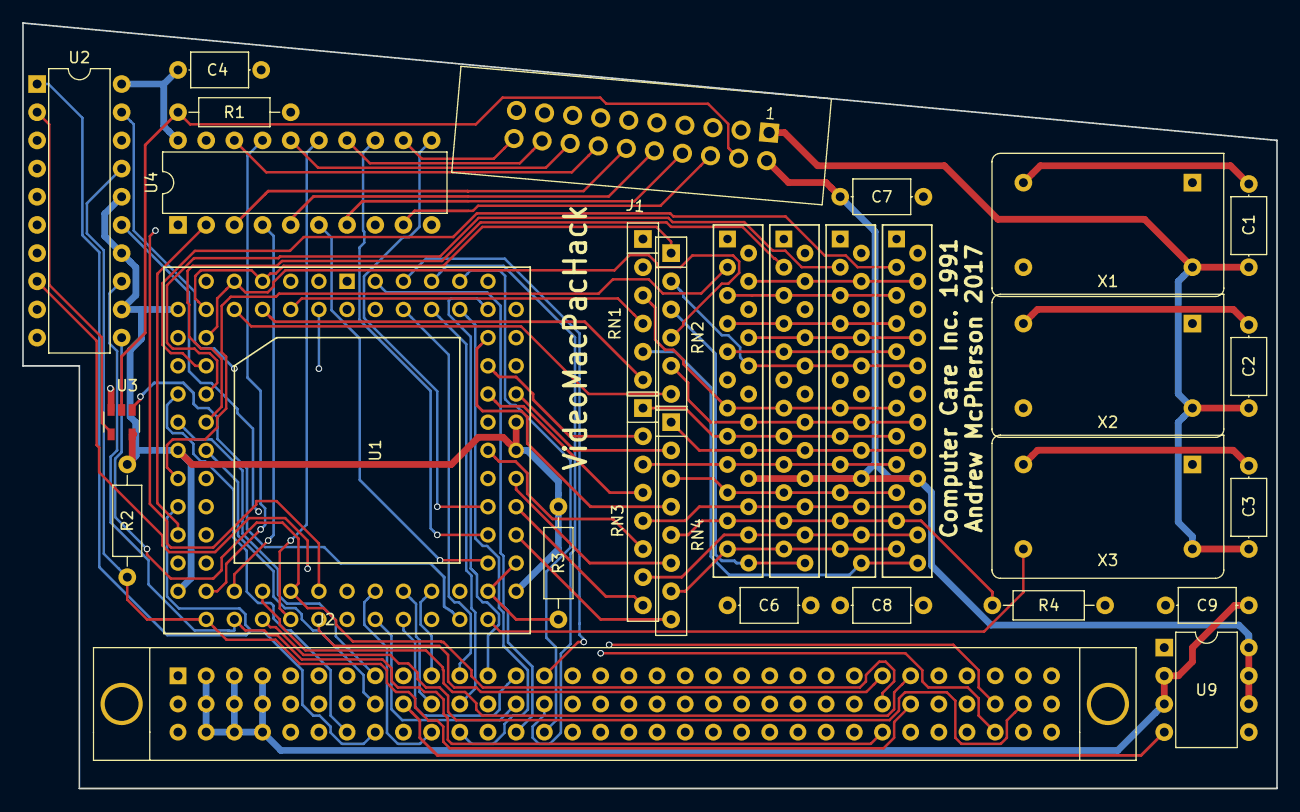
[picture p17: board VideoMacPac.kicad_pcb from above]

Board: 4 copper layers, 113.0 x 69.0 mm, 30 parts (0 on the bottom side), 110 nets.

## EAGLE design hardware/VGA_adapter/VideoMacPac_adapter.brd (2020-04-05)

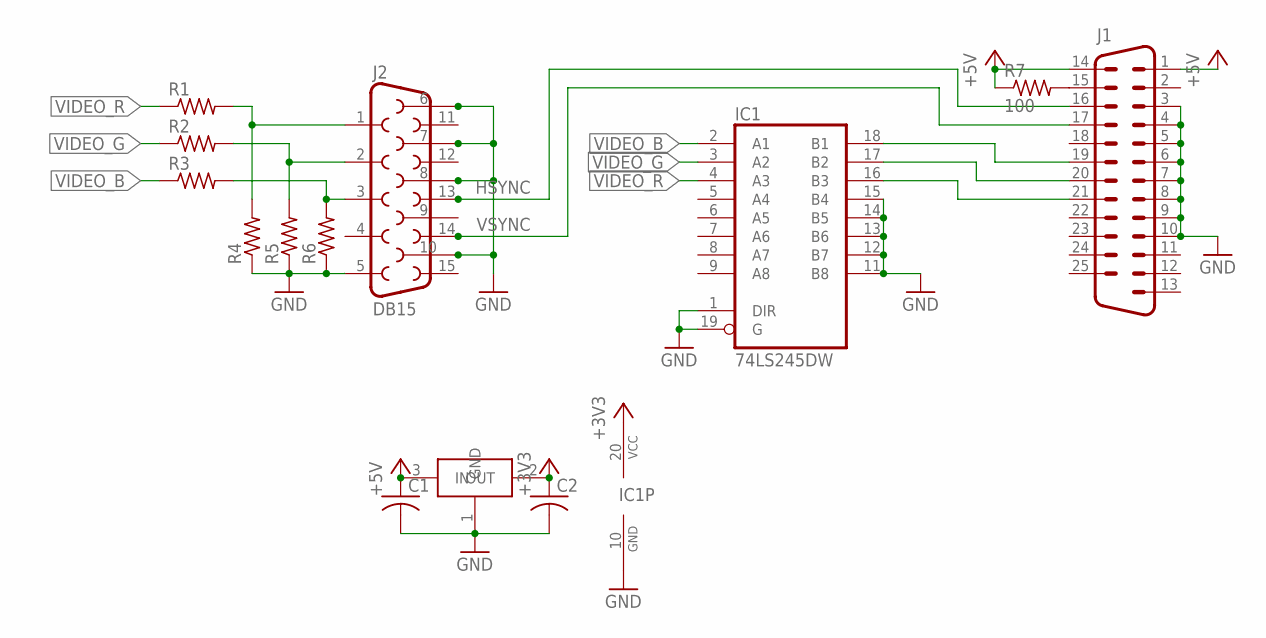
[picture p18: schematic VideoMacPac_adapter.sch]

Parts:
C1, C2: C-USC0603; C0603
IC1: 74LS245DW; SO20W
IC2: MCP1700; SOT23
J1: DB25H; M25H
J2: DB15
R1, R2, R3, R4, R5, R6: R-US_R0603; R0603
R7: 100; R0603

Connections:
+3V3: C2.1, IC1.20 (VCC), IC2.2 (OUT)
+5V: C1.1, IC2.3 (IN), J1.1, J1.14, R7.1
GND: C1.2, C2.2, IC1.1 (DIR), IC1.10 (GND), IC1.11 (B8), IC1.12 (B7), IC1.13 (B6), IC1.14 (B5), IC1.15 (B4), IC1.19 (G), IC2.1 (GND), J1.3, J1.4, J1.5, J1.6, J1.7, J1.8, J1.9, J1.10, J2.5, J2.6, J2.7, J2.8, J2.10, R4.1, R5.1, R6.1
HSYNC: J1.16, J2.13
unnamed: J1.15, R7.2
unnamed: IC1.16 (B3), J1.21
unnamed: J2.3, R3.2, R6.2
unnamed: IC1.17 (B2), J1.20
unnamed: J2.2, R2.2, R5.2
unnamed: J2.1, R1.2, R4.2
unnamed: IC1.18 (B1), J1.19
VIDEO_B: IC1.2 (A1), R3.1
VIDEO_G: IC1.3 (A2), R2.1
VIDEO_R: IC1.4 (A3), R1.1
VSYNC: J1.17, J2.14

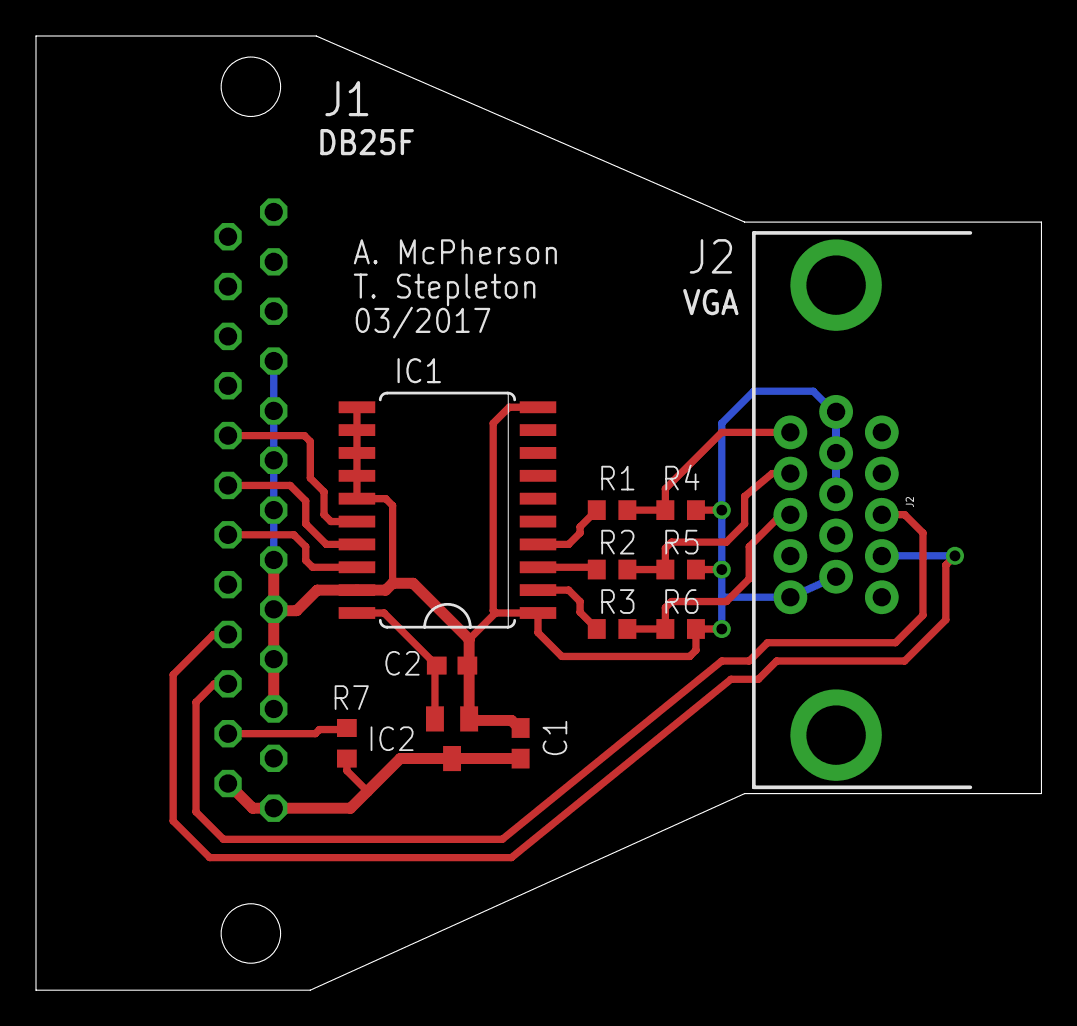
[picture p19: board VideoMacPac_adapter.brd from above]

Board: 2 copper layers, 55.9 x 53.0 mm, 13 parts (1 on the bottom side), 15 nets.

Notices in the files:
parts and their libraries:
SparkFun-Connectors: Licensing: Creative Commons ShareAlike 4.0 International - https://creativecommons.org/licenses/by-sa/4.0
